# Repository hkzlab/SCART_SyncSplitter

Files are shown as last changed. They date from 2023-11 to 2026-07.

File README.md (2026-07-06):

# SCART Composite Sync Splitter/Cleaner

## Introduction

This card takes an RGB + Composite signal from a SCART connector and outputs the same RGB signal + split HSync/VSync (or CSync) on an 
HD15 (VGA) connector. This is **not** a scandoubler, and is meant to be used with multisync monitors that require either separated
sync signals or a clean csync.

The board is based around the LMH1981 IC and takes from 7 to 12VDC, center tip positive, as power input.

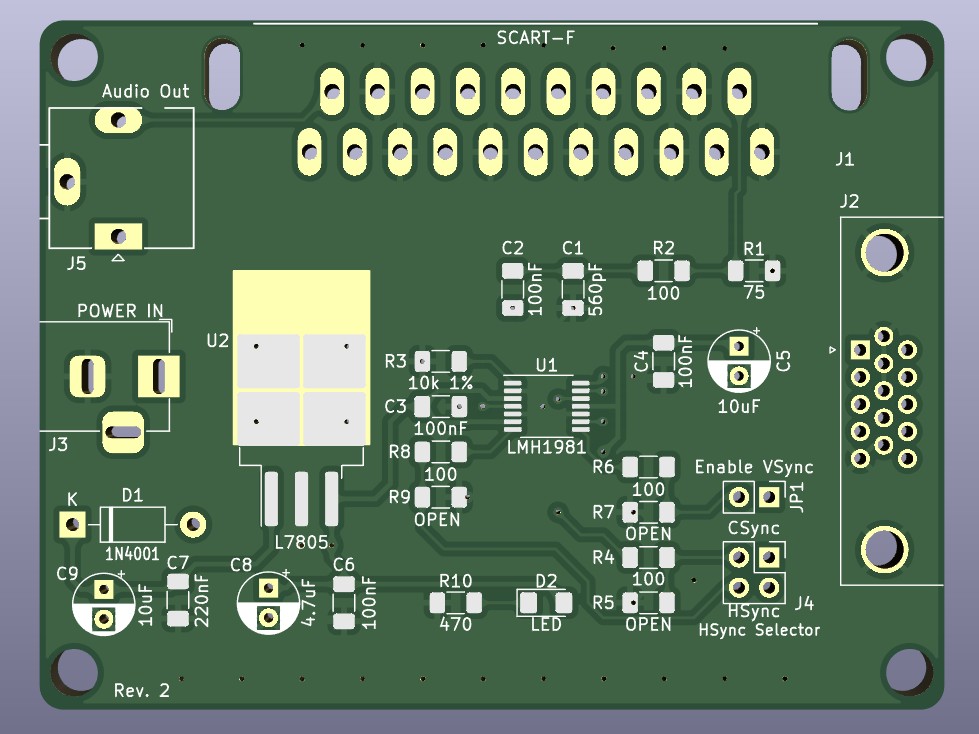
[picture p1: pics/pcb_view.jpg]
Sync Splitter


Currently tested with:

- Sony PlayStation 1 (PAL/50Hz)
- SEGA MegaDrive (PAL/60Hz mod)

Audio out is still **untested**.

You can order a PCB for this project [HERE](https://www.pcbway.com/project/shareproject/SCART_SyncSplitter_bdc49b8d.html).

### Disclaimer

I take NO responsibility for what happens if you decide to build and use this card. Your computer might crash, catch fire or be destroyed in other nasty ways.
You're encourauged to take what you deem fit from this, and use it in your projects!

### Sponsorship

PCBWay_logo

This project is kindly sponsored by [PCBWay](https://pcbway.com).
PCBWay specializes in manufacturing high-quality PCBs and makes them affordable to hobbyist and professionals alike.

The range of services they offer include PCB prototyping, assembly, instant quotes for your order, a verification process by a team
of experts and an easy to use, hassle-free order process.

I'm grateful to PCBWay for the support in creating this project.

### 💰 Selling these boards 💰

I you want to contact me about selling this project, you can reach me via email at `0hkzUNDERSCOREprojects6ATposteoDOTnet` after properly fixing the email address by removing the digits and replacing the uppercase words with the proper characters.

**Contacts via other channels will be ignored**, as it means you did not read this document thoroughly.

"Collaborations" will boil down to the following:

- If you wish to produce and share this project at a loss or at cost, go for it. I am only asking for attribution and to let me know via email.
- If you want to do it for profit, let's discuss it. I'll probably settle for a rough 5% of the profit. Importing components is getting more expensive by the day, so this will contribute to me making future projects available for free.
- I will NOT do customer assistance for you or your customers. This is a hobby, not my job.

If this is not ok for you, you're cordially invited to go bother someone else :)

Authorized sellers will be listed in this README. If you find someone selling my boards without being listed here, it means they're stealing other people's work.

## Known Issues

### Rev. 0

- Pin 13 and 14 of the VGA connector (HSync and VSync) are swapped. Solved in Rev. 1

## Bill of Materials

| Component | Qty | Type / Value |
| --- | --- | --- |
| C1 |  1  | 560pF / 1206 / ceramic |
| C2, C3, C4, C6 |  4  | 100nF / 1206 / ceramic |
| C5, C9 |  2  | 10uF radial e.l. caps  |
| C7 |  1  | 220nF / 1206 / ceramic |
| C8 |  1  | 4.7uF radial e.l. cap  |
| D1 |  1  | 1N400x THT diode |
| D2 |  1  | led / 1206 |
| J1 |  1  | SCART female angled |
| J2 |  1  | HD15 female, PCB mount |
| J3 |  1  | power jack connector |
| J4 |  1  | 2x2 2.54mm headers |
| J5 |  1  | stereo audio jack pcb  |
| JP1 |  1  | 1x2 2.54mm headers |
| R1 |  1  | 75ohm / 1206 |
| R2, R4, R6, R8 |  4  | 100ohm / 1206 |
| R3 |  1  | 10k ohm 1% tol / 1206  |
| R10 |  1  | 470ohm / 1206 |
| U1 |  1  | LMH1981 |
| U2 |  1  | 7805 TO-263 |

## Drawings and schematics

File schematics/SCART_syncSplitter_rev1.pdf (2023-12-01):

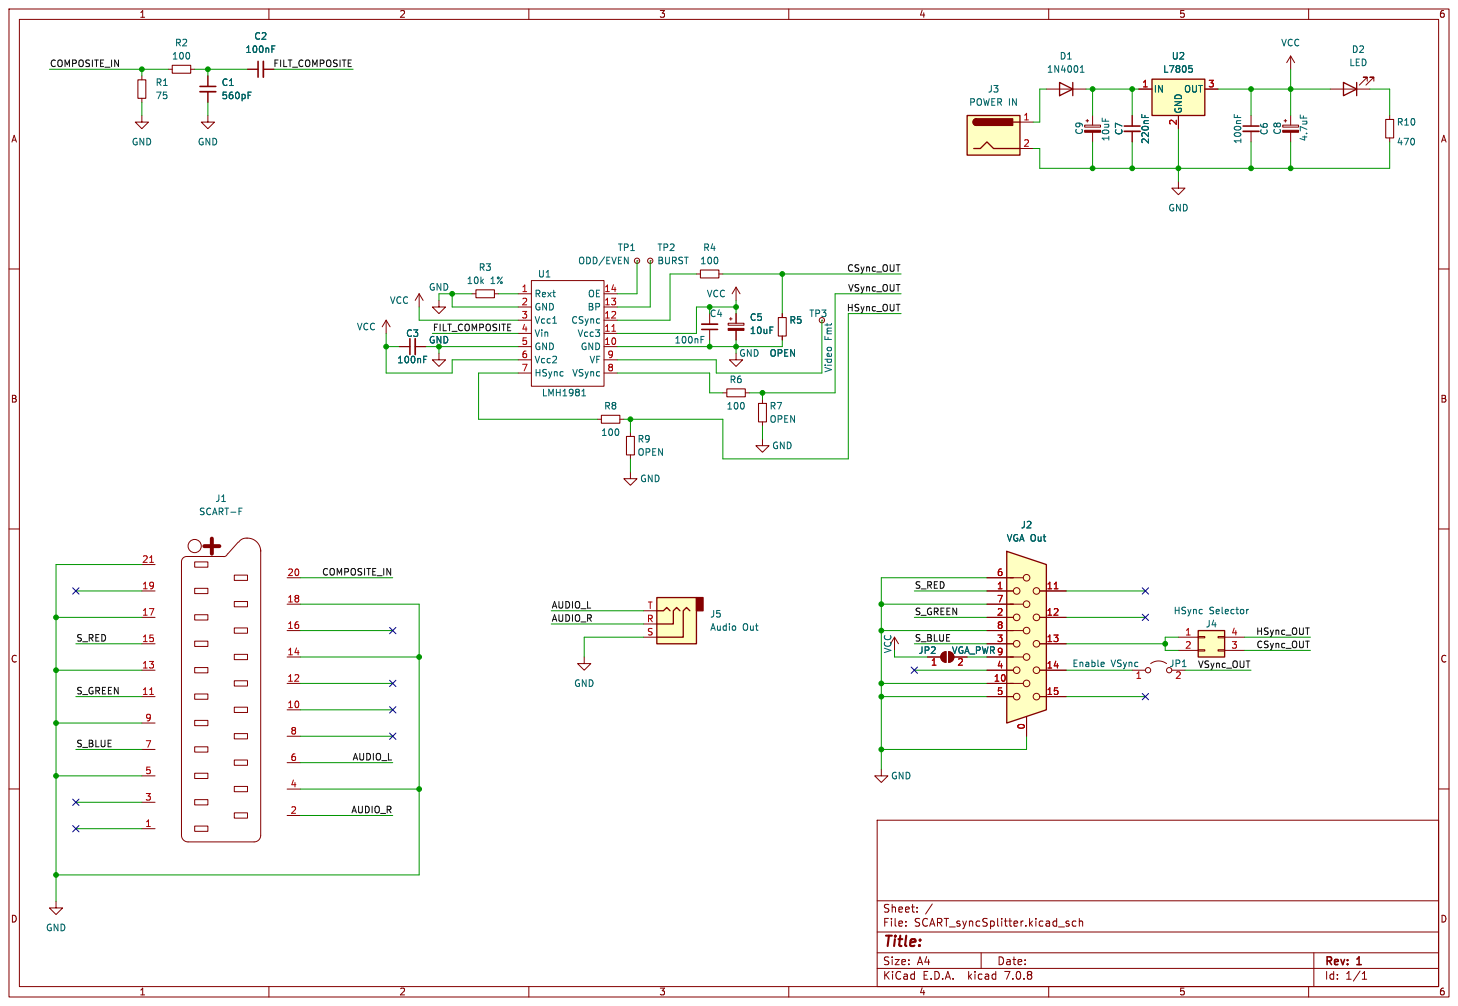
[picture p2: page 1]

Id: 1/1 Title: File: SCART_syncSplitter.kicad_sch Sheet: /

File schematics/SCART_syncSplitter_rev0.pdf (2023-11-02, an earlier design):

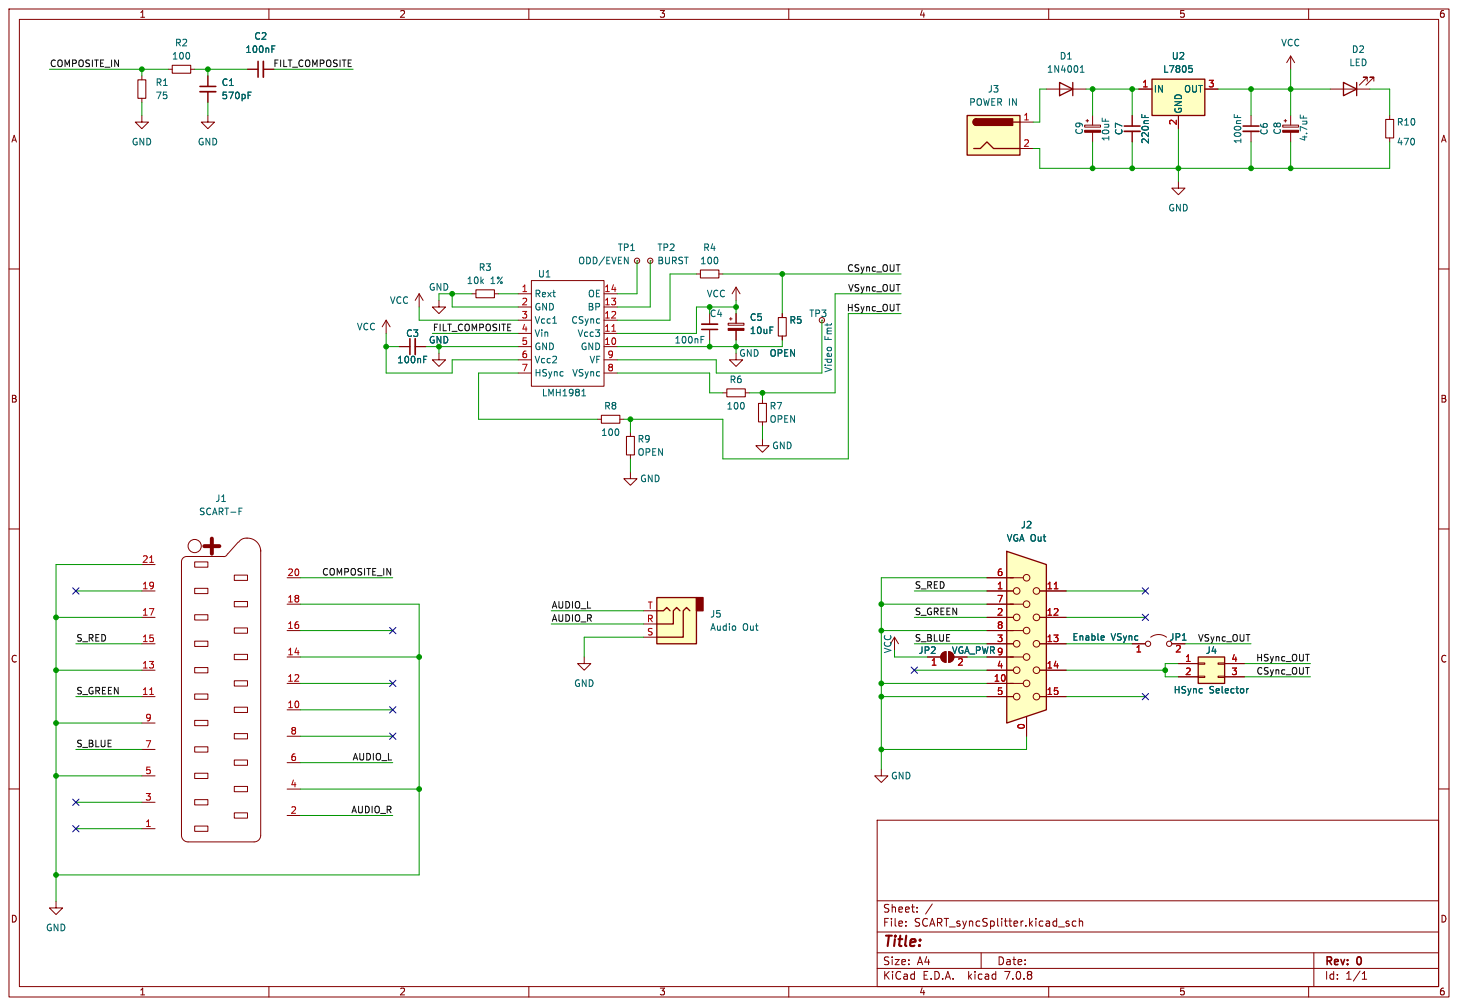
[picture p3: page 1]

Id: 1/1 Title: File: SCART_syncSplitter.kicad_sch Sheet: /

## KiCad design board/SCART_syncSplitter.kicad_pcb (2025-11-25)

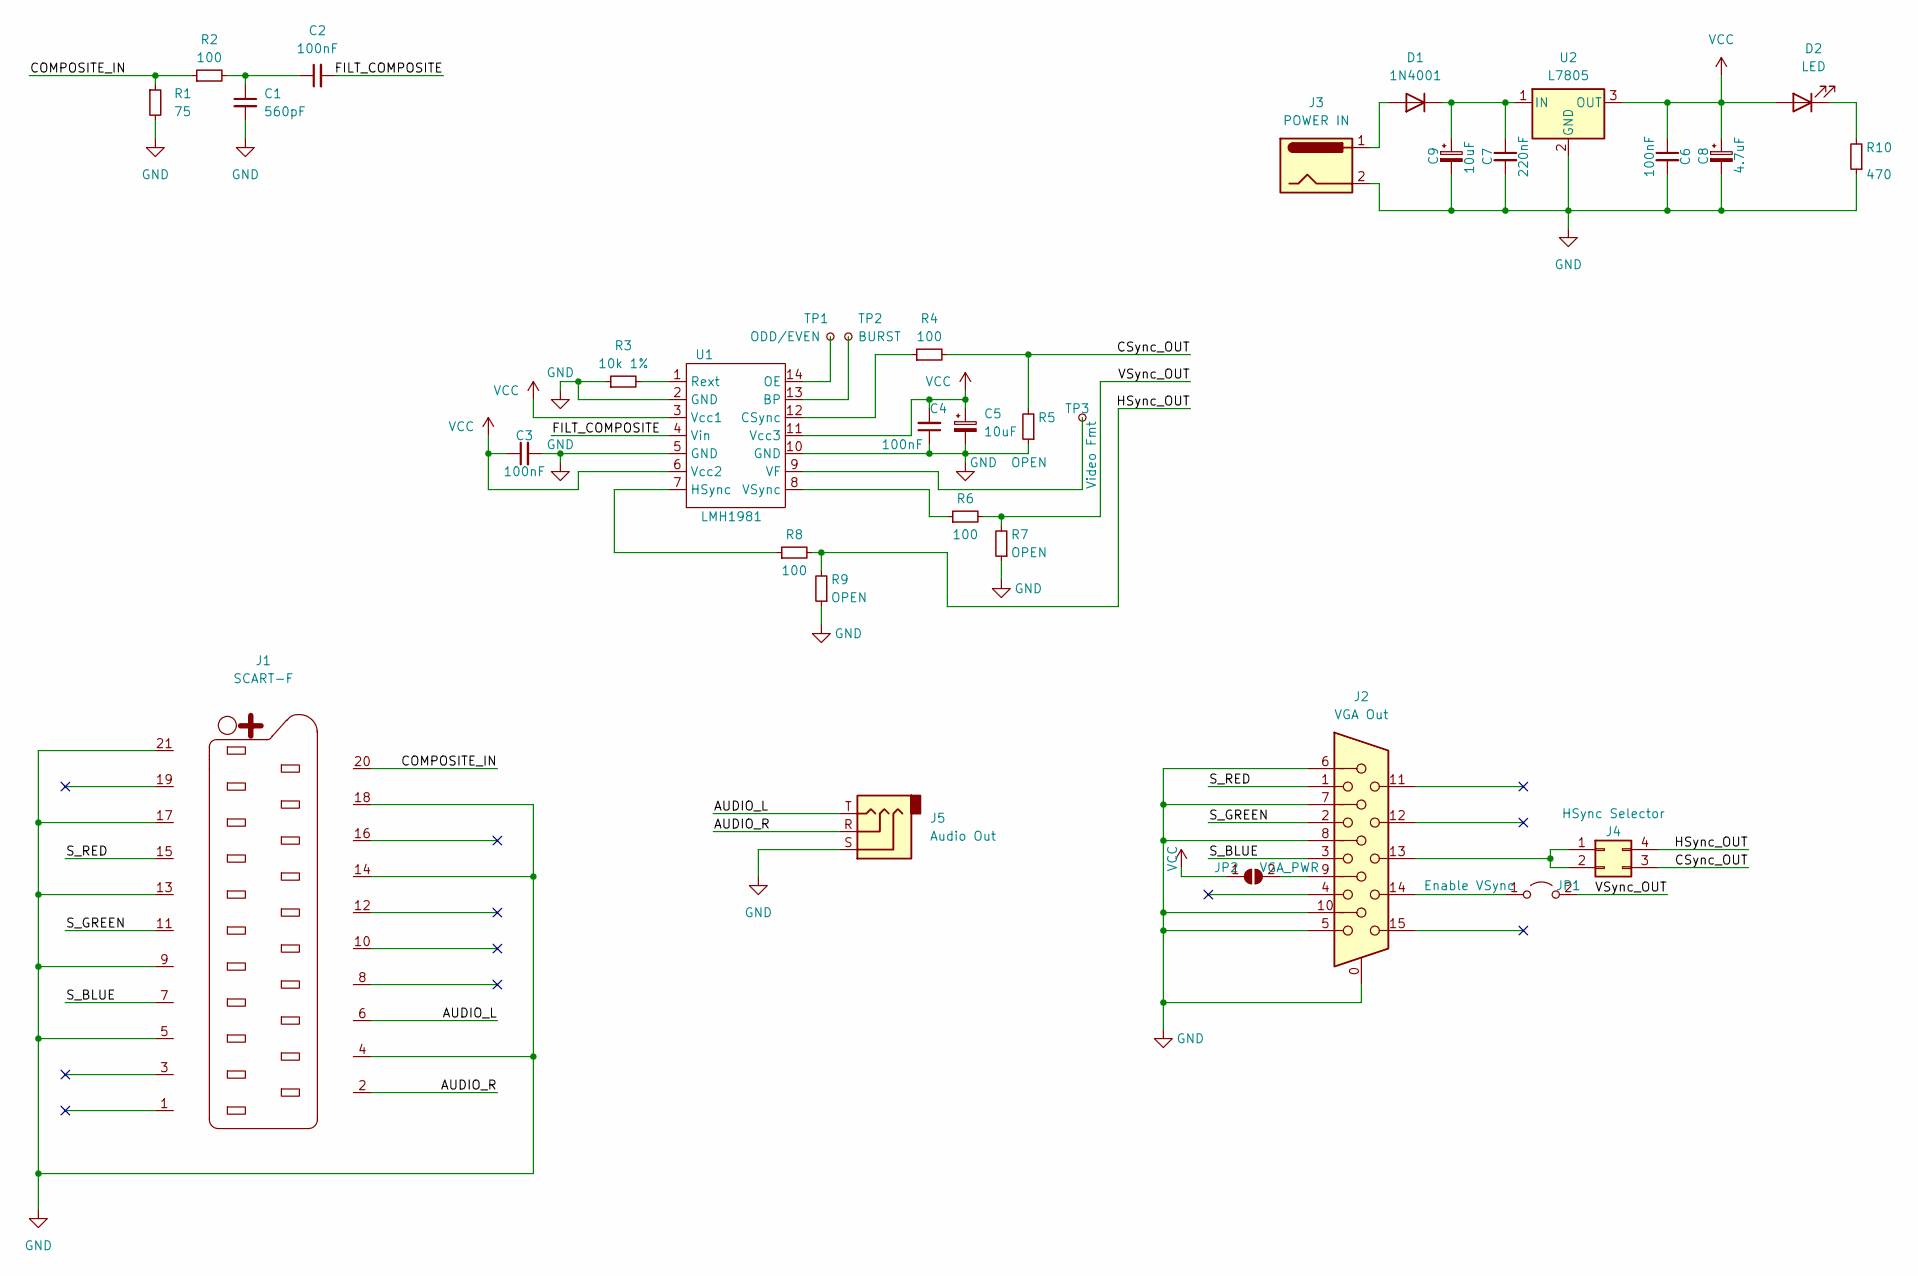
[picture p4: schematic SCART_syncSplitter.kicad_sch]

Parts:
C1: 560pF; C_1206_3216Metric_Pad1.33x1.80mm_HandSolder
C2, C3, C4, C6: 100nF; C_1206_3216Metric_Pad1.33x1.80mm_HandSolder
C5, C9: 10uF; CP_Radial_D5.0mm_P2.50mm
C7: 220nF; C_1206_3216Metric_Pad1.33x1.80mm_HandSolder
C8: 4.7uF; CP_Radial_D5.0mm_P2.50mm
D1: 1N4001; D_DO-41_SOD81_P10.16mm_Horizontal
D2: LED; LED_1206_3216Metric_Pad1.42x1.75mm_HandSolder
J1: SCART-F; SCART_F_RA
J2: VGA Out; DSUB-15-HD_Female_Horizontal_P2.29x1.98mm_EdgePinOffset3.03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
J3: POWER IN; BarrelJack_Horizontal
J4: HSync Selector; PinHeader_2x02_P2.54mm_Vertical
J5: Audio Out; Custom_3.5mm_jack
JP1: Enable VSync; PinHeader_1x02_P2.54mm_Vertical
JP2: VGA_PWR; SolderJumper-2_P1.3mm_Open_RoundedPad1.0x1.5mm
R1: 75; R_1206_3216Metric_Pad1.30x1.75mm_HandSolder
R2, R4, R6, R8: 100; R_1206_3216Metric_Pad1.30x1.75mm_HandSolder
R3: 10k 1%; R_1206_3216Metric_Pad1.30x1.75mm_HandSolder
R5, R7, R9: OPEN; R_1206_3216Metric_Pad1.30x1.75mm_HandSolder
R10: 470; R_1206_3216Metric_Pad1.30x1.75mm_HandSolder
TP1: ODD/EVEN; TestPoint_Pad_1.0x1.0mm
TP2: BURST; TestPoint_Pad_1.0x1.0mm
TP3: Video Fmt; TestPoint_Pad_1.0x1.0mm
U1: LMH1981; TSSOP-14_4.4x5mm_P0.65mm
U2: L7805; TO-263-3_TabPin2

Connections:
/AUDIO_L: J1.6, J5.T
/AUDIO_R: J1.2, J5.R
/COMPOSITE_IN: J1.20, R1.1, R2.1
/CSync_OUT: J4.3, R4.2, R5.2
/FILT_COMPOSITE: C2.2, U1.4 (Vin)
/HSync_OUT: J4.4, R8.2, R9.2
/S_BLUE: J1.7, J2.3
/S_GREEN: J1.11, J2.2
/S_RED: J1.15, J2.1
/VSync_OUT: JP1.2 (B), R6.2, R7.2
GND: C1.2, C3.2, C4.1, C5.2, C6.2, C7.2, C8.2, C9.2, J1.4, J1.5, J1.9, J1.13, J1.14, J1.17, J1.18, J1.21, J2.0, J2.5, J2.6, J2.7, J2.8, J2.10, J3.2, J5.S, R1.2, R3.1, R5.1, R7.1, R9.1, R10.1, U1.2 (GND), U1.5 (GND), U1.10 (GND), U2.2 (GND)
unnamed: C1.1, C2.1, R2.2
unnamed: D1.2 (A), J3.1
unnamed: C7.1, C9.1, D1.1 (K), U2.1 (IN)
unnamed: D2.1 (K), R10.2
unnamed: J2.13, J4.1, J4.2
unnamed: J2.14, JP1.1 (A)
unnamed: J2.9, JP2.2 (B)
unnamed: TP2.1, U1.13 (BP)
unnamed: R4.1, U1.12 (CSync)
unnamed: R8.1, U1.7 (HSync)
unnamed: TP1.1, U1.14 (OE)
unnamed: R3.2, U1.1 (Rext)
unnamed: TP3.1, U1.9 (VF)
unnamed: R6.1, U1.8 (VSync)
VCC: C3.1, C4.2, C5.1, C6.1, C8.1, D2.2 (A), JP2.1 (A), U1.3 (Vcc1), U1.6 (Vcc2), U1.11 (Vcc3), U2.3 (OUT)

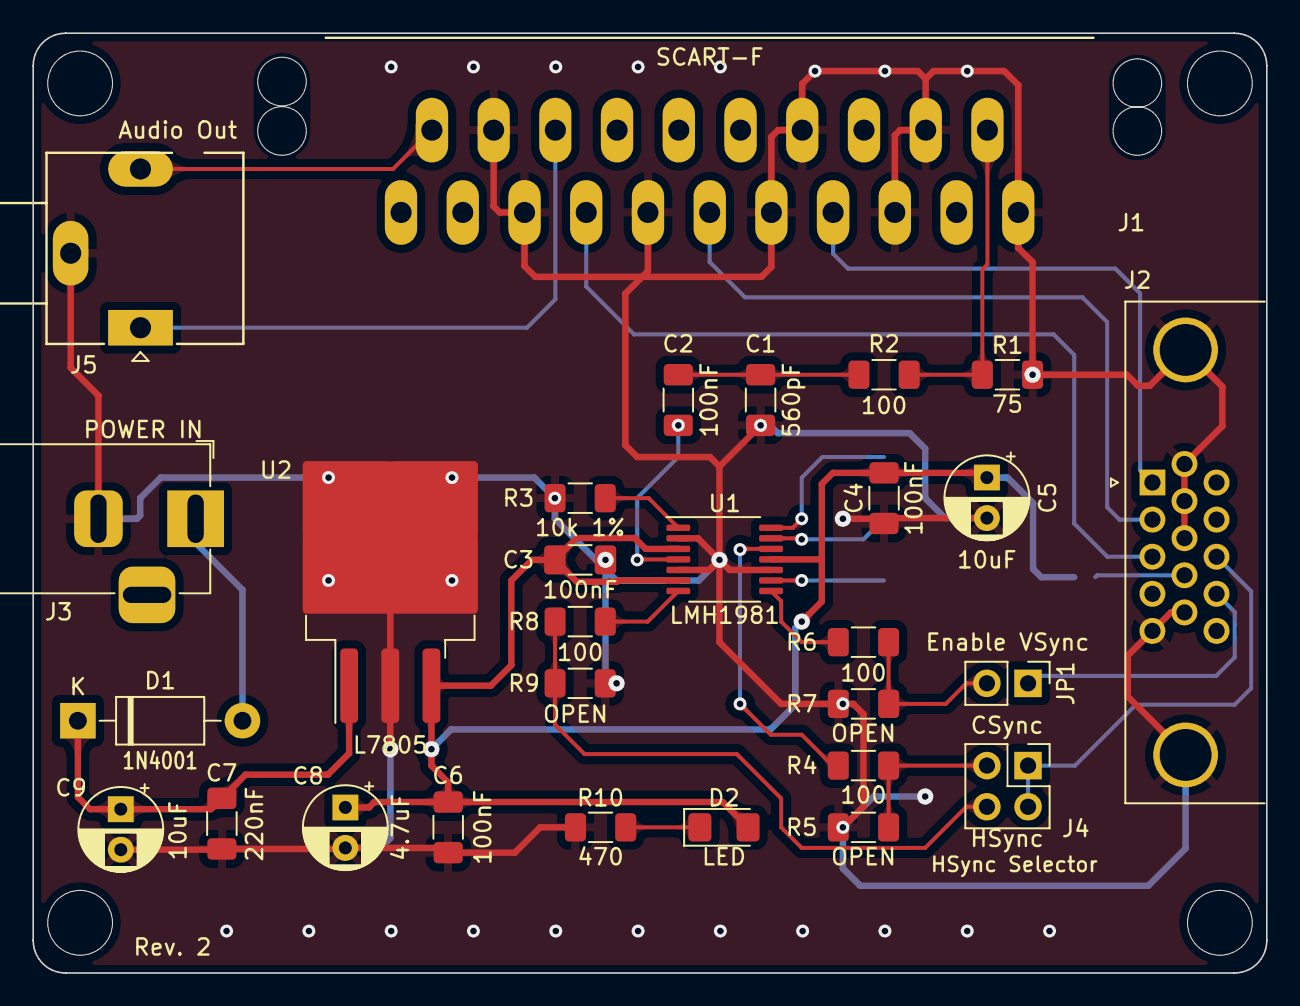
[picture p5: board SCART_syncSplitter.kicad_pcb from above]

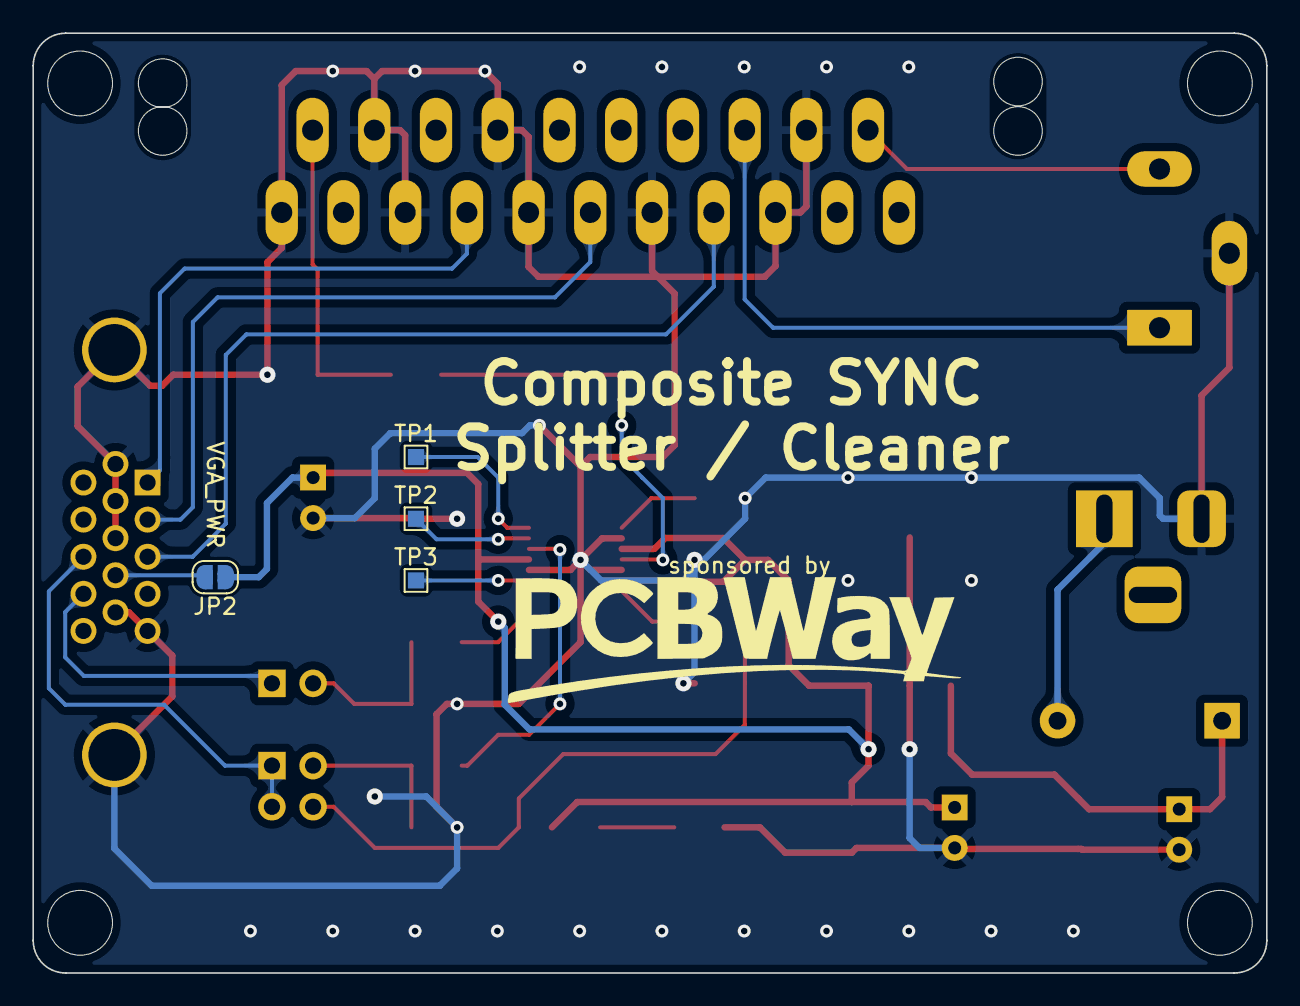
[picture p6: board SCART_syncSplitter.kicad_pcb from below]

Board: 2 copper layers, 76.1 x 58.0 mm, 33 parts (4 on the bottom side), 26 nets.

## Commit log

2023-10-18 Import and create required symbols
    [SCART_syncSplitter.kicad_pcb, SCART_syncSplitter.kicad_sch]
2023-10-22 Update the schematic
    [SCART_syncSplitter.kicad_sch]
2023-10-22 Add VGA Out
    [SCART_syncSplitter.kicad_sch]
2023-10-22 Added audio out
    [SCART_syncSplitter.kicad_sch]
2023-10-23 Imported some libraries, started assigning footprints
    [SCART_syncSplitter.kicad_sch]
2023-10-24 Assigned footprints
    [SCART_syncSplitter.kicad_sch]
2023-10-24 Start preparing the PCB
    [SCART_syncSplitter.kicad_pcb, SCART_syncSplitter.kicad_sch]
2023-10-24 Add Power led
    [SCART_syncSplitter.kicad_pcb, SCART_syncSplitter.kicad_sch]
2023-10-24 Update the PCB
    [SCART_syncSplitter.kicad_pcb]
2023-10-24 Begin routing traces
    [SCART_syncSplitter.kicad_pcb]
2023-10-25 Drawn pcb
    [SCART_syncSplitter.kicad_pcb]
2023-10-26 Update PCB and schematic
    [SCART_syncSplitter.kicad_pcb, SCART_syncSplitter.kicad_sch]
2023-11-02 Added PCBWay logo
    [SCART_syncSplitter.kicad_pcb]
2023-11-02 Renamed directory
    [SCART_syncSplitter-B_Cu.gbr, SCART_syncSplitter-B_Mask.gbr, SCART_syncSplitter-B_Paste.gbr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]
2023-11-02 Remove old gerbers
    [SCART_syncSplitter-B_Cu.gbr, SCART_syncSplitter-B_Mask.gbr, SCART_syncSplitter-B_Paste.gbr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]
2023-11-02 Add schematics
2023-11-03 Added gerbers
2023-12-01 Rev 1 of the schematics: invert vsync/hsync pins on VGA
    [SCART_syncSplitter.kicad_sch]
2023-12-01 Update project for rev.1 board
    [SCART_syncSplitter.kicad_pcb, SCART_syncSplitter.kicad_sch]
2025-11-25 Prepare a rev.2 with mounting holes
    [SCART_syncSplitter.kicad_pcb]
2025-11-25 Reorganize some tracks
    [SCART_syncSplitter.kicad_pcb]
2025-11-25 Tweak some tracks
    [SCART_syncSplitter.kicad_pcb]
2025-11-25 Rework some tracks
    [SCART_syncSplitter.kicad_pcb]
2025-11-25 Add rev.2 board
    [SCART_syncSplitter.kicad_pcb]
2025-11-25 Update the PCB view
